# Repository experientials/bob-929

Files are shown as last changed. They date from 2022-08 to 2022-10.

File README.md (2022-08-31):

# Bob

Bob is an independent device that sees and senses the environment. It recognises objects and behavior based on what it has been taught. 

It receives stereo video input over 2 x 2-lane MIPI CSI2. Additionally it receives sensor input over I2C
for distance, color, brightness. The sensor inputs are processed and disected to identify objects, people and
behaviour. Ziloo can connect over USB to make the output available.

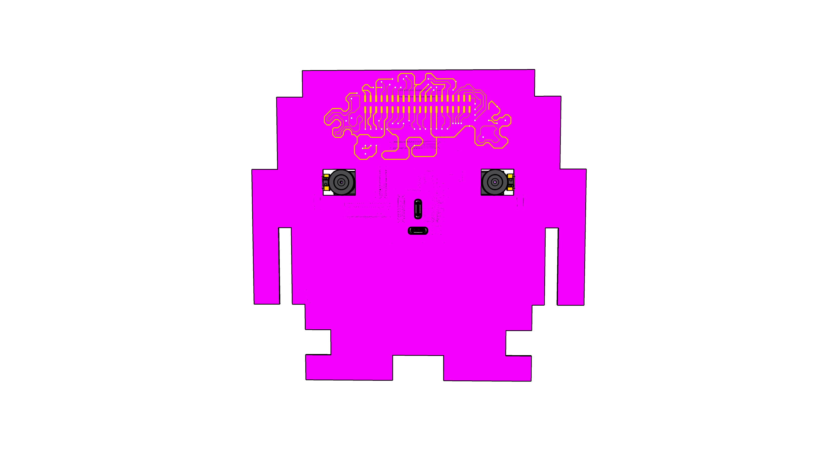
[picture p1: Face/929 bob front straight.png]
Bob face


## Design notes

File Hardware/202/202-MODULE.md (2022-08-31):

# 202 Combi Camera Module

The board
- 18mm x 57mm, 25mm wide hole for the T-USB module, 3.5mm bridge between the parts 
- 1 * 60 pin connector
- 2 * 34 pin connectors
- 34 pin connectors are 4.25 mm from bottom
- 34 pin connector centers are 51 mm apart
- 

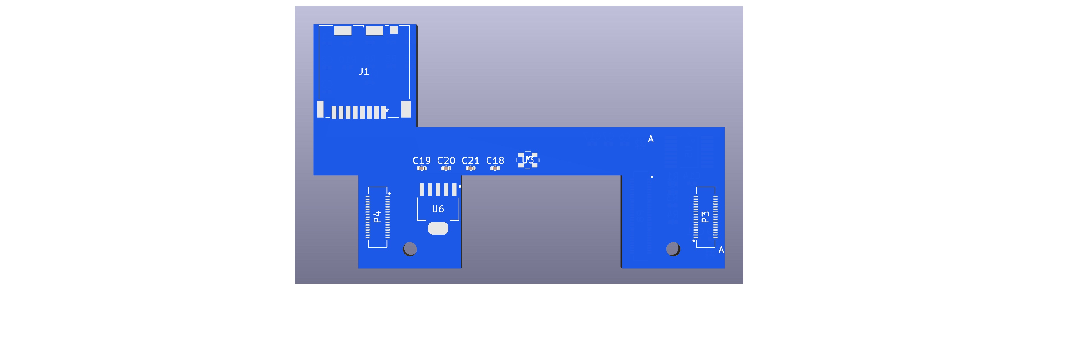
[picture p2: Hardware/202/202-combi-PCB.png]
202 Combi PCB


## BOM

- 1 * [XTAL OSC 24MHz ASE-24.000MHZ-LC-T]() - [Mouser](https://www.mouser.ch/ProductDetail/ABRACON/ASE-24.000MHZ-LC-T) - 1.2mm height - [Datasheet](https://abracon.com/Oscillators/ASEseries.pdf) - In stock
- 1 * [LDO Voltage Reg TPS79628DCQ 2.8V as SOT-223-6]() - [Mouser](https://www.mouser.ch/ProductDetail/Texas-Instruments/TPS79628DCQ) - In stock
- 1 * [IO Expander TCA9534PWR TSSOP 16 pin](https://www.ti.com/product/TCA9534) - 1.2mm height - [Datasheet](https://www.ti.com/lit/ds/symlink/tca9534.pdf) - In stock
- 1 * [Hirose Micro SD Card slot DM3CS-SF]() - [Mouser](https://www.mouser.ch/ProductDetail/Hirose-Connector/DM3CS-SF) - In stock
- 1 * [Ti Low Power MSP430 MCU MSP430FR2422IRHLR](https://www.ti.com/product/MSP430FR2422/part-details/MSP430FR2422IRHLR) - 15 GPIO - In stock
- 1 * [DF40C-60DP-0.4V]() [JLCPCB part](https://jlcpcb.com/parts/componentSearch?isSearch=true&searchTxt=DF40C-60DP-0.4V)
- 2 * [Hirose DF40C-34DS-0.4V](https://www.hirose.com/en/product/p/CL0684-4023-0-51) ([Mouser](https://www.mouser.ch/ProductDetail/Hirose-Connector/DF40C-34DS-04V51?qs=vcbW%252B4%252BSTIpg26DsEbj1iQ%3D%3D))

Component selection

- TPS796xx power reg vs RT8272 based on availability (Ti needs fewer components)
- TCA9534 over TCA9554 8-bit to save price. No apparent feature difference
- TCA9535 16-bit is SSOP/TSSOP in stock

Device tree and GPIO:

https://stackoverflow.com/questions/30130358/device-tree-and-gpio

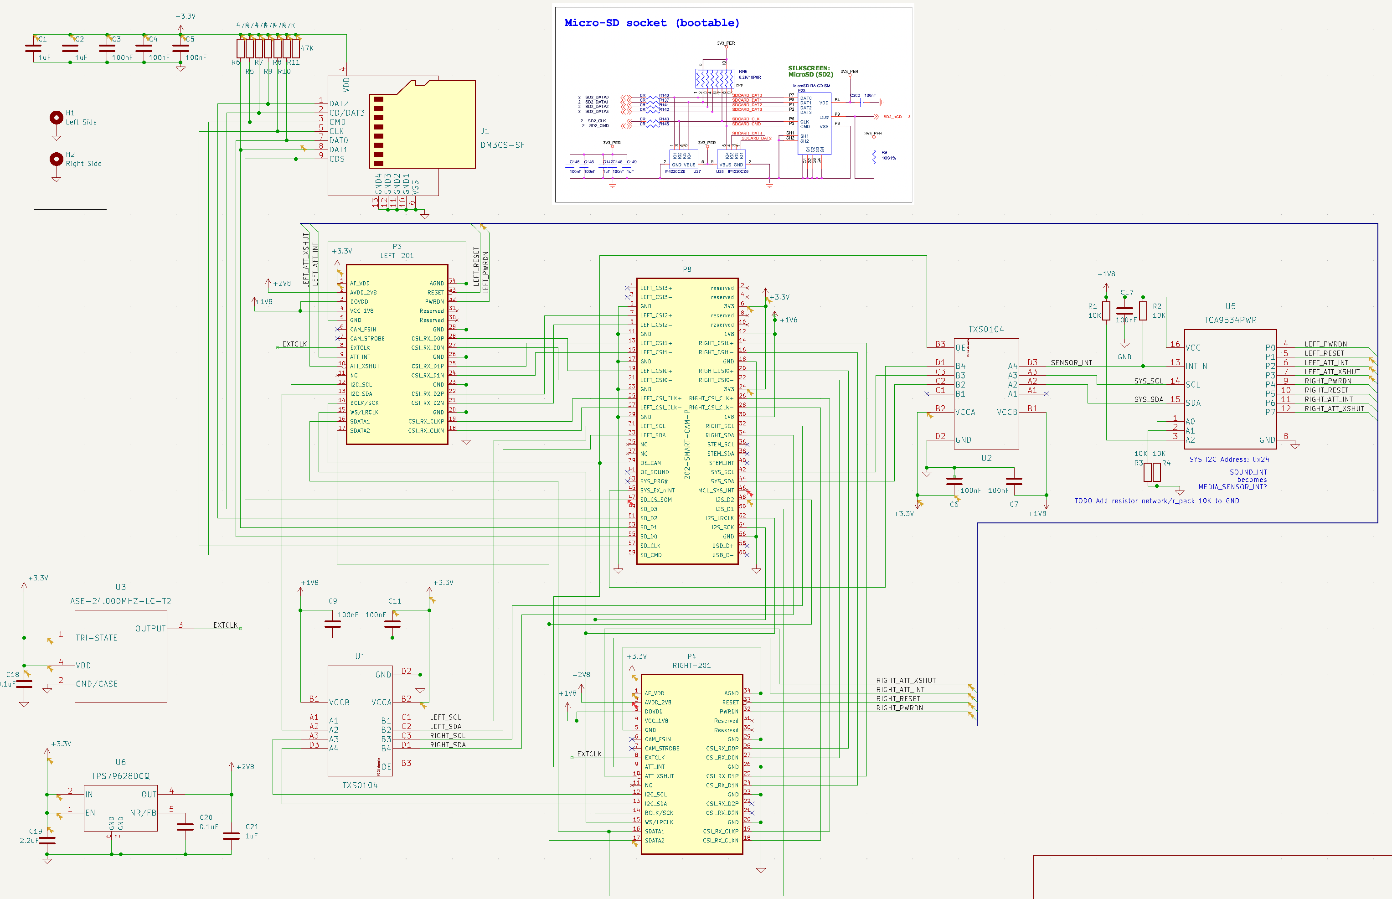
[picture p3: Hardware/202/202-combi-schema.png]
202 Combi Schema


## Upwork Job

You will revise my PCB design done with KiCAD v6. I have a schematic and basic PCB layout with the outline.
The board takes two connectors to camera modules and combine them into a single connector adding SD Card slot, I/O Expander, oscilator, voltage regulator and signal voltage translation.
I will want to add an MCU in the future so if you can reserve space for it on the board that will be very helpful.
I need a review for signal interference and quality of high speed signal lanes. I have not tried to route the
PCB, that will be your job.

- Correct design rules according to JLCPCB manufacturing
- Check the correctness of footprints against datasheets
- Check the need for capacitors on board reducing redundant ones
- Check that the schema/board has good ESD/noise reduction circuits
- Place resistors and capacitors where appropriate
- Update/Resolve Design checklist
- Ensure that differential pairs are routed together and balanced correctly
- Add 2 mounting holes next to P3 and P3 (symmetric)
- P3, P4 and P8 are aligned horizontally with overlapping centers
- Route the board

Symbols and footprints are found in https://github.com/experientials/kicad-lib.

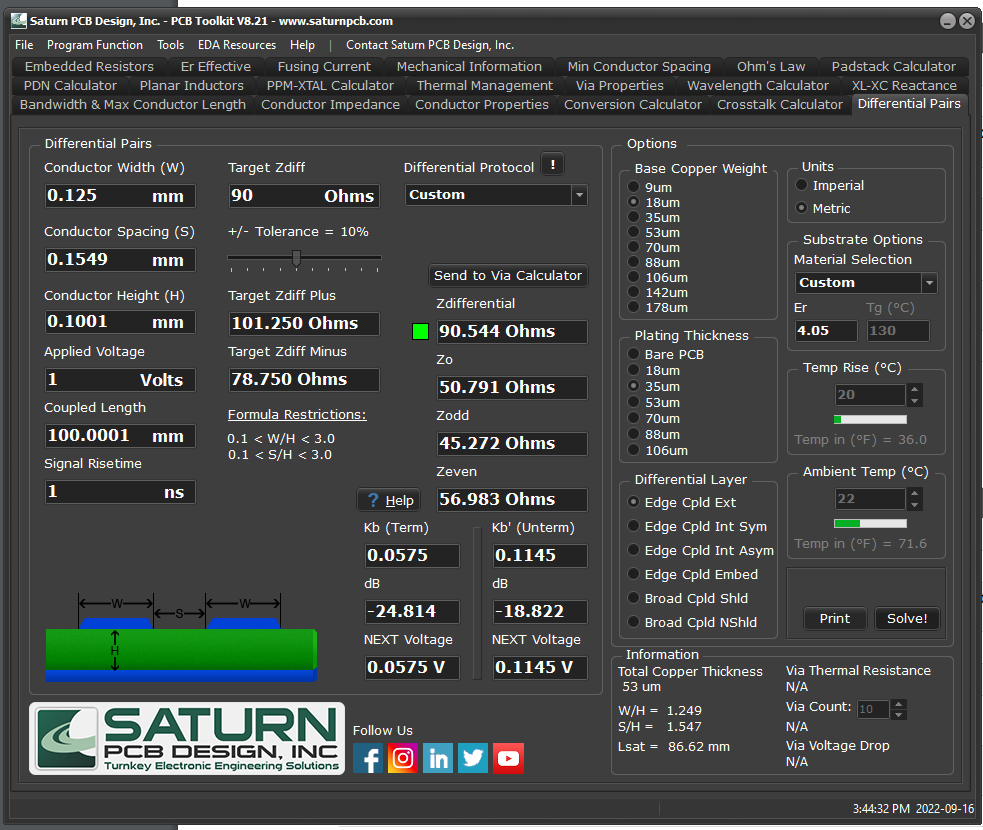
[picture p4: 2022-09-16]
Hardware/202/202-combi-v0.2/Stack-Up & Impendances/90Ohm_Diff.png

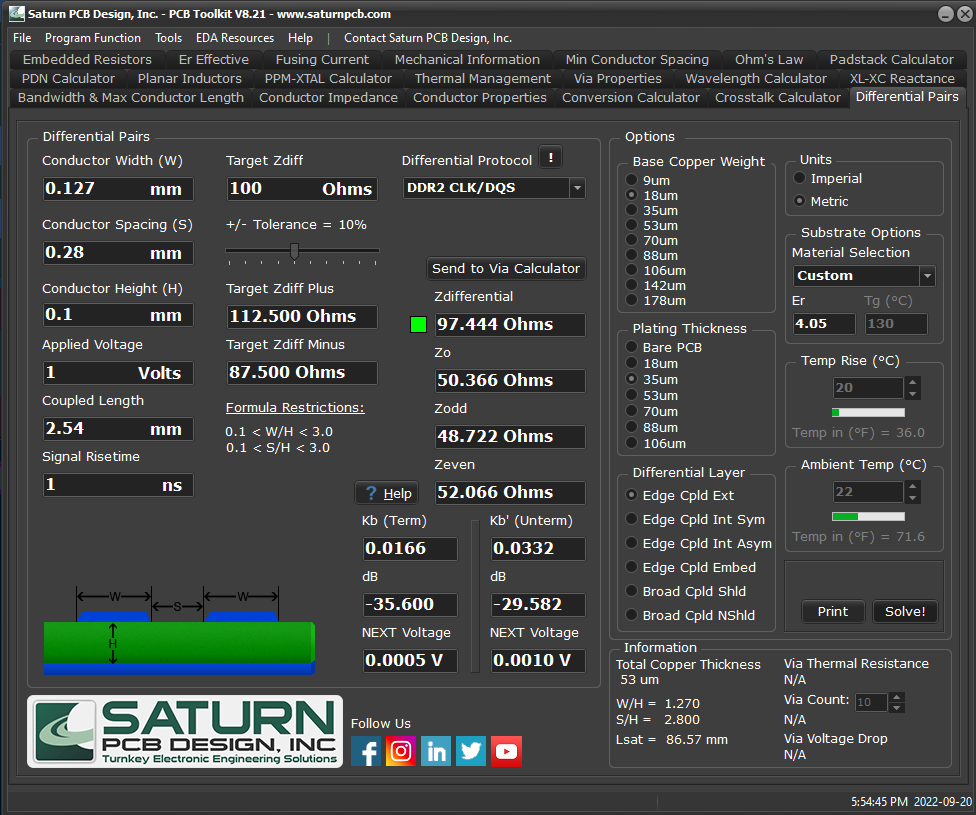
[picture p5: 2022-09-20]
Hardware/202/202-combi-v0.2/Stack-Up & Impendances/100Ohm_Diff.png

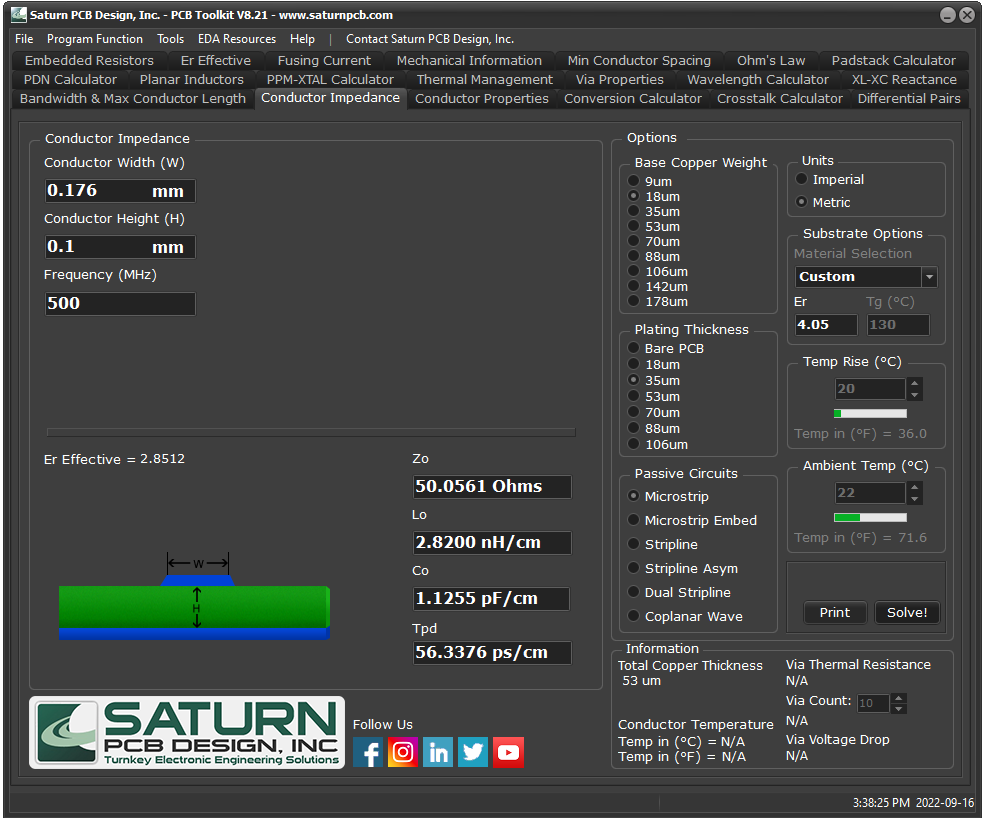
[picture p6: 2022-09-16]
Hardware/202/202-combi-v0.2/Stack-Up & Impendances/50Ohm_SE.png

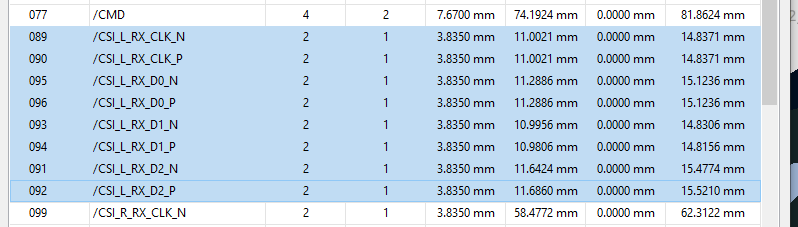
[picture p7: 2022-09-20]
Hardware/202/202-combi-v0.2/Stack-Up & Impendances/Left diff pair matching.png

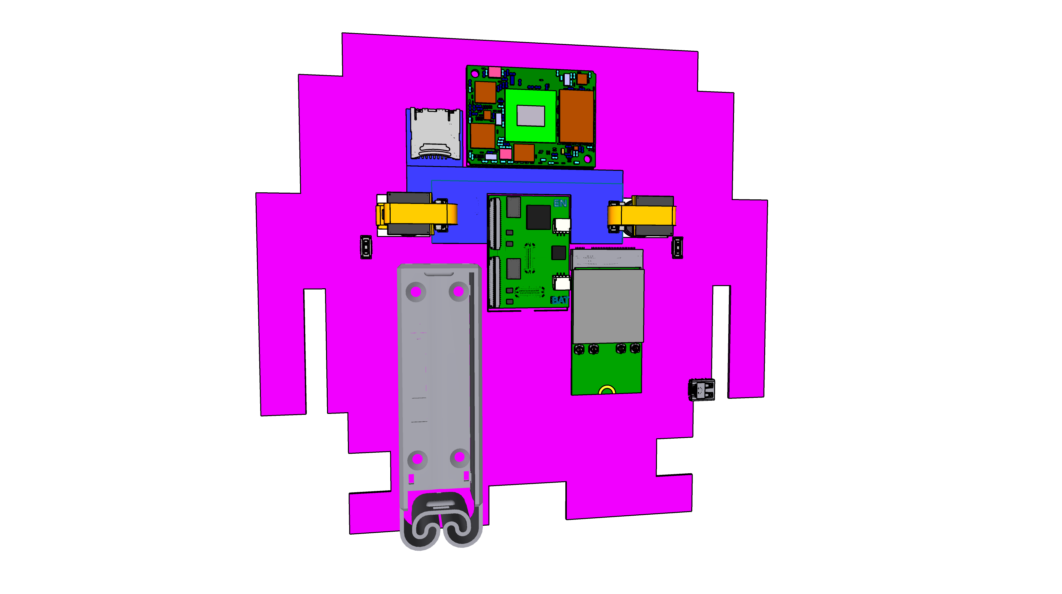
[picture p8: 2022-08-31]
Face/929 bob back.png

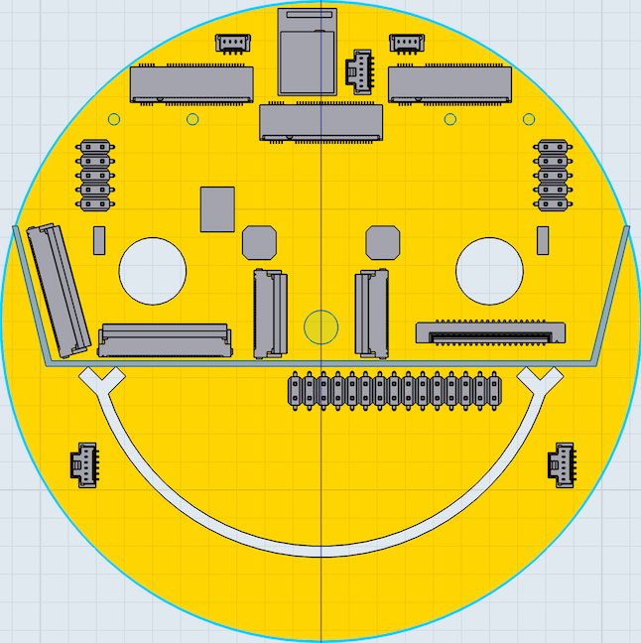
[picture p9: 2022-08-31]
Face/Ziloo back.png

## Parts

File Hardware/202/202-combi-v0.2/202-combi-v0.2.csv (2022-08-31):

Source: | /Volumes/Projects/ziloo/Hardware/202/202-combi/202-combi.kicad_sch
Date: | 2022 August 31, Wednesday 20:45:27
Tool: | Eeschema (6.0.6-0)
Generator: | /Applications/KiCad/KiCad.app/Contents/SharedSupport/plugins/bom_csv_grouped_by_value.py
Component Count: | 36
Individual Components:
Item | Qty | Reference(s) | Value | LibPart | Footprint | Datasheet | MANUFACTURER
 |  | C1 | 1uF | Device:C | Capacitor_SMD:C_0402_1005Metric | ~
 |  | C2 | 1uF | Device:C | Capacitor_SMD:C_0402_1005Metric | ~
 |  | C3 | 100nF | Device:C | Capacitor_SMD:C_0402_1005Metric | ~
 |  | C4 | 100nF | Device:C | Capacitor_SMD:C_0402_1005Metric | ~
 |  | C5 | 100nF | Device:C | Capacitor_SMD:C_0402_1005Metric | ~
 |  | C6 | 100nF | Device:C | Capacitor_SMD:C_0402_1005Metric | ~
 |  | C7 | 100nF | Device:C | Capacitor_SMD:C_0402_1005Metric | ~
 |  | C9 | 100nF | Device:C | Capacitor_SMD:C_0402_1005Metric | ~
 |  | C11 | 100nF | Device:C | Capacitor_SMD:C_0402_1005Metric | ~
 |  | C17 | 100nF | Device:C | Capacitor_SMD:C_0402_1005Metric | ~
 |  | C18 | 0.1uF | Device:C | Capacitor_SMD:C_0402_1005Metric | ~
 |  | C19 | 2.2uF | Device:C | Capacitor_SMD:C_0402_1005Metric | ~
 |  | C20 | 0.1uF | Device:C | Capacitor_SMD:C_0402_1005Metric | ~
 |  | C21 | 1uF | Device:C | Capacitor_SMD:C_0402_1005Metric | ~
 |  | H1 | Left Side | Mechanical:MountingHole_Pad | MountingHole:MountingHole_2.2mm_M2 | ~
 |  | H2 | Right Side | Mechanical:MountingHole_Pad | MountingHole:MountingHole_2.2mm_M2 | ~
 |  | J1 | DM3CS-SF | Ziloo:DM3CS-SF | Ziloo:DM3CS-SF
 |  | P3 | LEFT-201 | :201-SOCKET-34DS-0.4V(51)_1 | Ziloo:HIROSE_DF40C-34DS-0.4V(51) |  | Hirose Electric Co Ltd
 |  | P4 | RIGHT-201 | Ziloo:201-SOCKET-34DS-0.4V(51) | Ziloo:HIROSE_DF40C-34DS-0.4V(51) |  | Hirose Electric Co Ltd
 |  | P8 | 202-SMART-CAM-P | Ziloo:202-SMART-CAM-P | Ziloo:DF40C-60DP-0.4V51 | https://www.hirose.com/en/product/document?clcode=CL0684-4004-6-51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 | Hirose Electric Co Ltd
 |  | R1 | 10K | Device:R | Resistor_SMD:R_0402_1005Metric | ~
 |  | R2 | 10K | Device:R | Resistor_SMD:R_0402_1005Metric | ~
 |  | R3 | 10K | Device:R | Resistor_SMD:R_0402_1005Metric | ~
 |  | R4 | 10K | Device:R | Resistor_SMD:R_0402_1005Metric | ~
 |  | R5 | 47K | Device:R | Resistor_SMD:R_0402_1005Metric | ~
 |  | R6 | 47K | Device:R | Resistor_SMD:R_0402_1005Metric | ~
 |  | R7 | 47K | Device:R | Resistor_SMD:R_0402_1005Metric | ~
 |  | R8 | 47K | Device:R | Resistor_SMD:R_0402_1005Metric | ~
 |  | R9 | 47K | Device:R | Resistor_SMD:R_0402_1005Metric | ~
 |  | R10 | 47K | Device:R | Resistor_SMD:R_0402_1005Metric | ~
 |  | R11 | 47K | Device:R | Resistor_SMD:R_0402_1005Metric | ~
 |  | U1 | TXS0104 | Ziloo:TXS0104EYZTR | Ziloo:TXS0104EYZTR
 |  | U2 | TXS0104 | Ziloo:TXS0104EYZTR | Ziloo:TXS0104EYZTR
 |  | U3 | ASE-24.000MHZ-LC-T2 | Ziloo:ASE-24.000MHZ-LC-T2 | Ziloo:ASE-24.000MHZ-LC-T2
 |  | U5 | TCA9534PWR | Ziloo:TCA9534PWR | Ziloo:TCA9534PWR
 |  | U6 | TPS79628DCQ | Ziloo:TPS79628DCQ | Ziloo:SOT127P706X180-6N
Collated Components:
Item | Qty | Reference(s) | Value | LibPart | Footprint | Datasheet | MANUFACTURER
1 | 3 | C1, C2, C21 | 1uF | Device:C | Capacitor_SMD:C_0402_1005Metric | ~
2 | 8 | C3, C4, C5, C6, C7, C9, C11, C17 | 100nF | Device:C | Capacitor_SMD:C_0402_1005Metric | ~
3 | 2 | C18, C20 | 0.1uF | Device:C | Capacitor_SMD:C_0402_1005Metric | ~
4 | 1 | C19 | 2.2uF | Device:C | Capacitor_SMD:C_0402_1005Metric | ~
5 | 1 | H1 | Left Side | Mechanical:MountingHole_Pad | MountingHole:MountingHole_2.2mm_M2 | ~
6 | 1 | H2 | Right Side | Mechanical:MountingHole_Pad | MountingHole:MountingHole_2.2mm_M2 | ~
7 | 1 | J1 | DM3CS-SF | Ziloo:DM3CS-SF | Ziloo:DM3CS-SF
8 | 1 | P3 | LEFT-201 | :201-SOCKET-34DS-0.4V(51)_1 | Ziloo:HIROSE_DF40C-34DS-0.4V(51) |  | Hirose Electric Co Ltd
9 | 1 | P4 | RIGHT-201 | Ziloo:201-SOCKET-34DS-0.4V(51) | Ziloo:HIROSE_DF40C-34DS-0.4V(51) |  | Hirose Electric Co Ltd
10 | 1 | P8 | 202-SMART-CAM-P | Ziloo:202-SMART-CAM-P | Ziloo:DF40C-60DP-0.4V51 | https://www.hirose.com/en/product/document?clcode=CL0684-4004-6-51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 | Hirose Electric Co Ltd
11 | 4 | R1, R2, R3, R4 | 10K | Device:R | Resistor_SMD:R_0402_1005Metric | ~
12 | 7 | R5, R6, R7, R8, R9, R10, R11 | 47K | Device:R | Resistor_SMD:R_0402_1005Metric | ~
13 | 2 | U1, U2 | TXS0104 | Ziloo:TXS0104EYZTR | Ziloo:TXS0104EYZTR
14 | 1 | U3 | ASE-24.000MHZ-LC-T2 | Ziloo:ASE-24.000MHZ-LC-T2 | Ziloo:ASE-24.000MHZ-LC-T2
15 | 1 | U5 | TCA9534PWR | Ziloo:TCA9534PWR | Ziloo:TCA9534PWR
16 | 1 | U6 | TPS79628DCQ | Ziloo:TPS79628DCQ | Ziloo:SOT127P706X180-6N

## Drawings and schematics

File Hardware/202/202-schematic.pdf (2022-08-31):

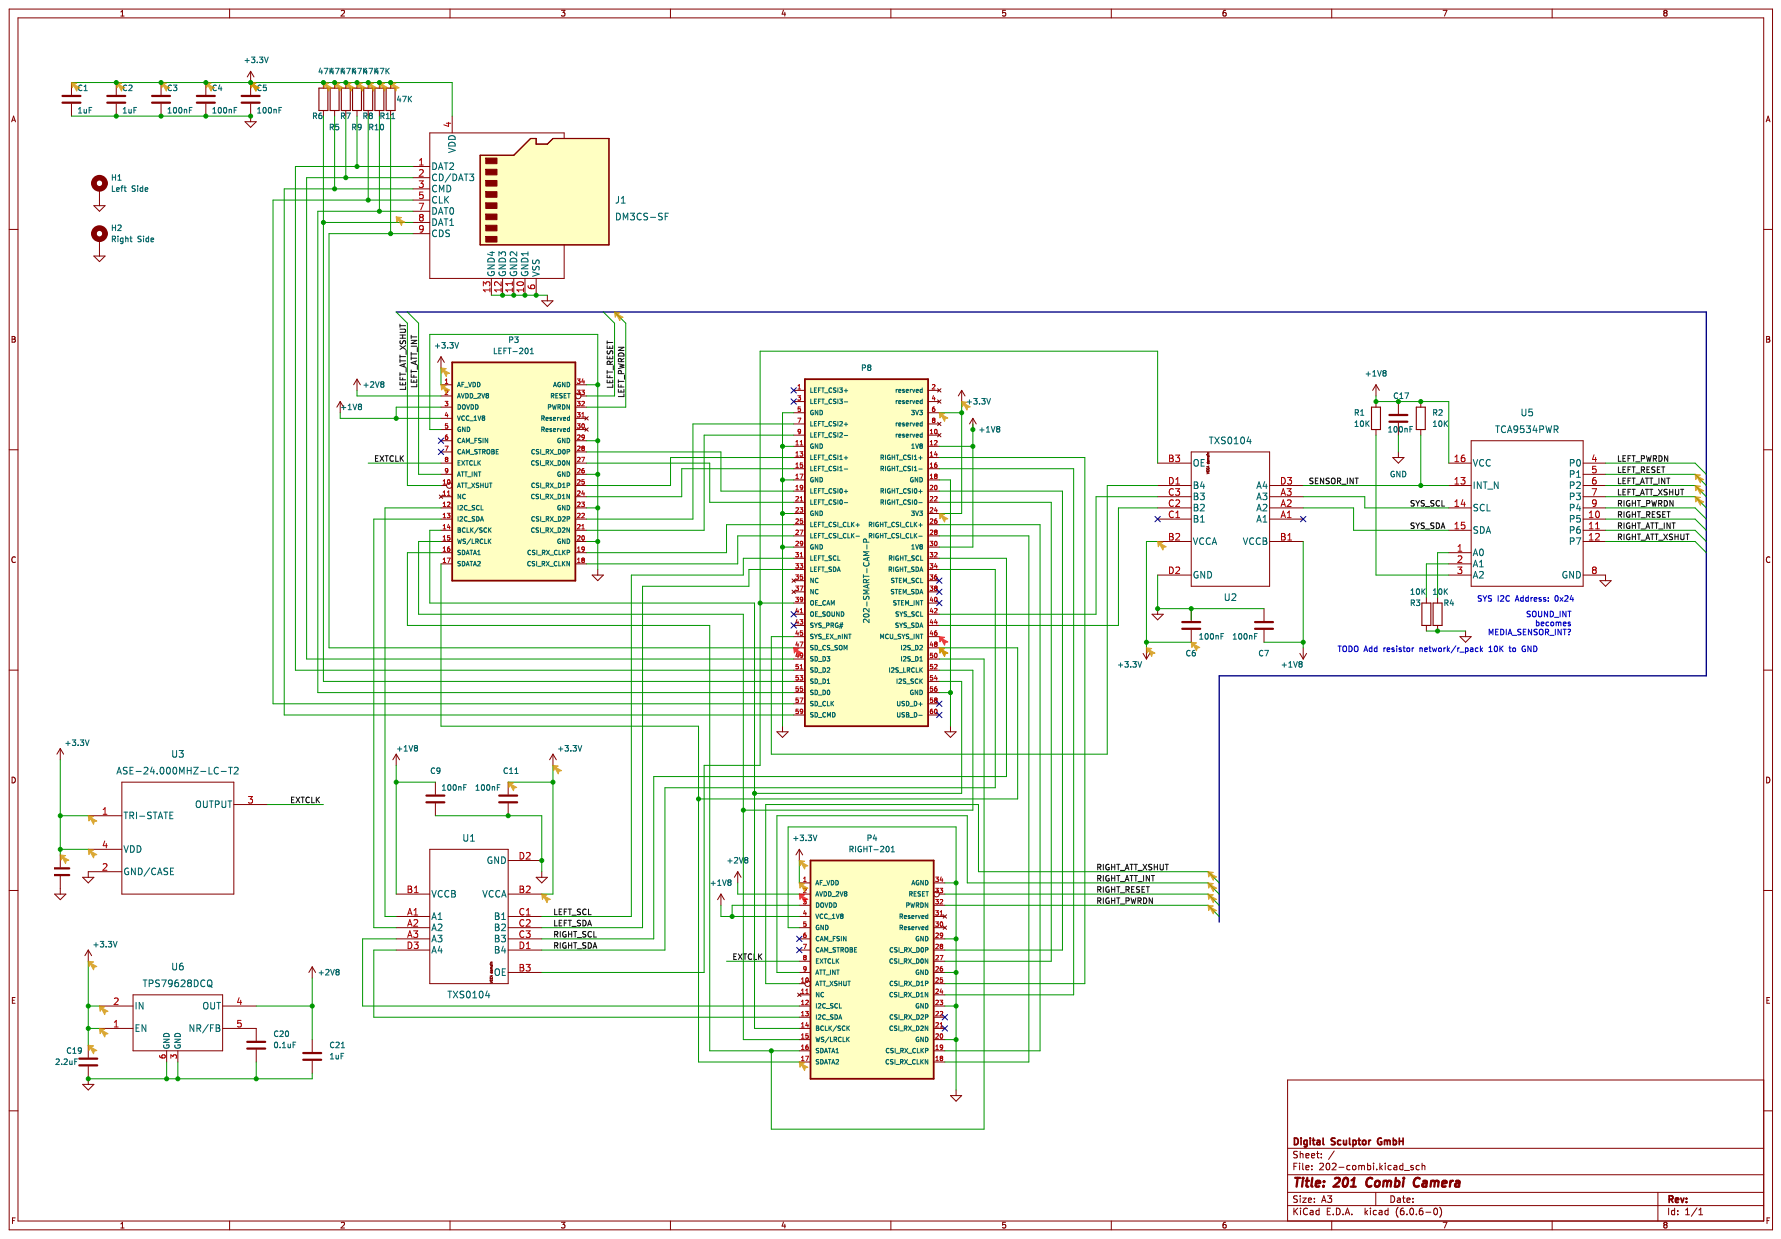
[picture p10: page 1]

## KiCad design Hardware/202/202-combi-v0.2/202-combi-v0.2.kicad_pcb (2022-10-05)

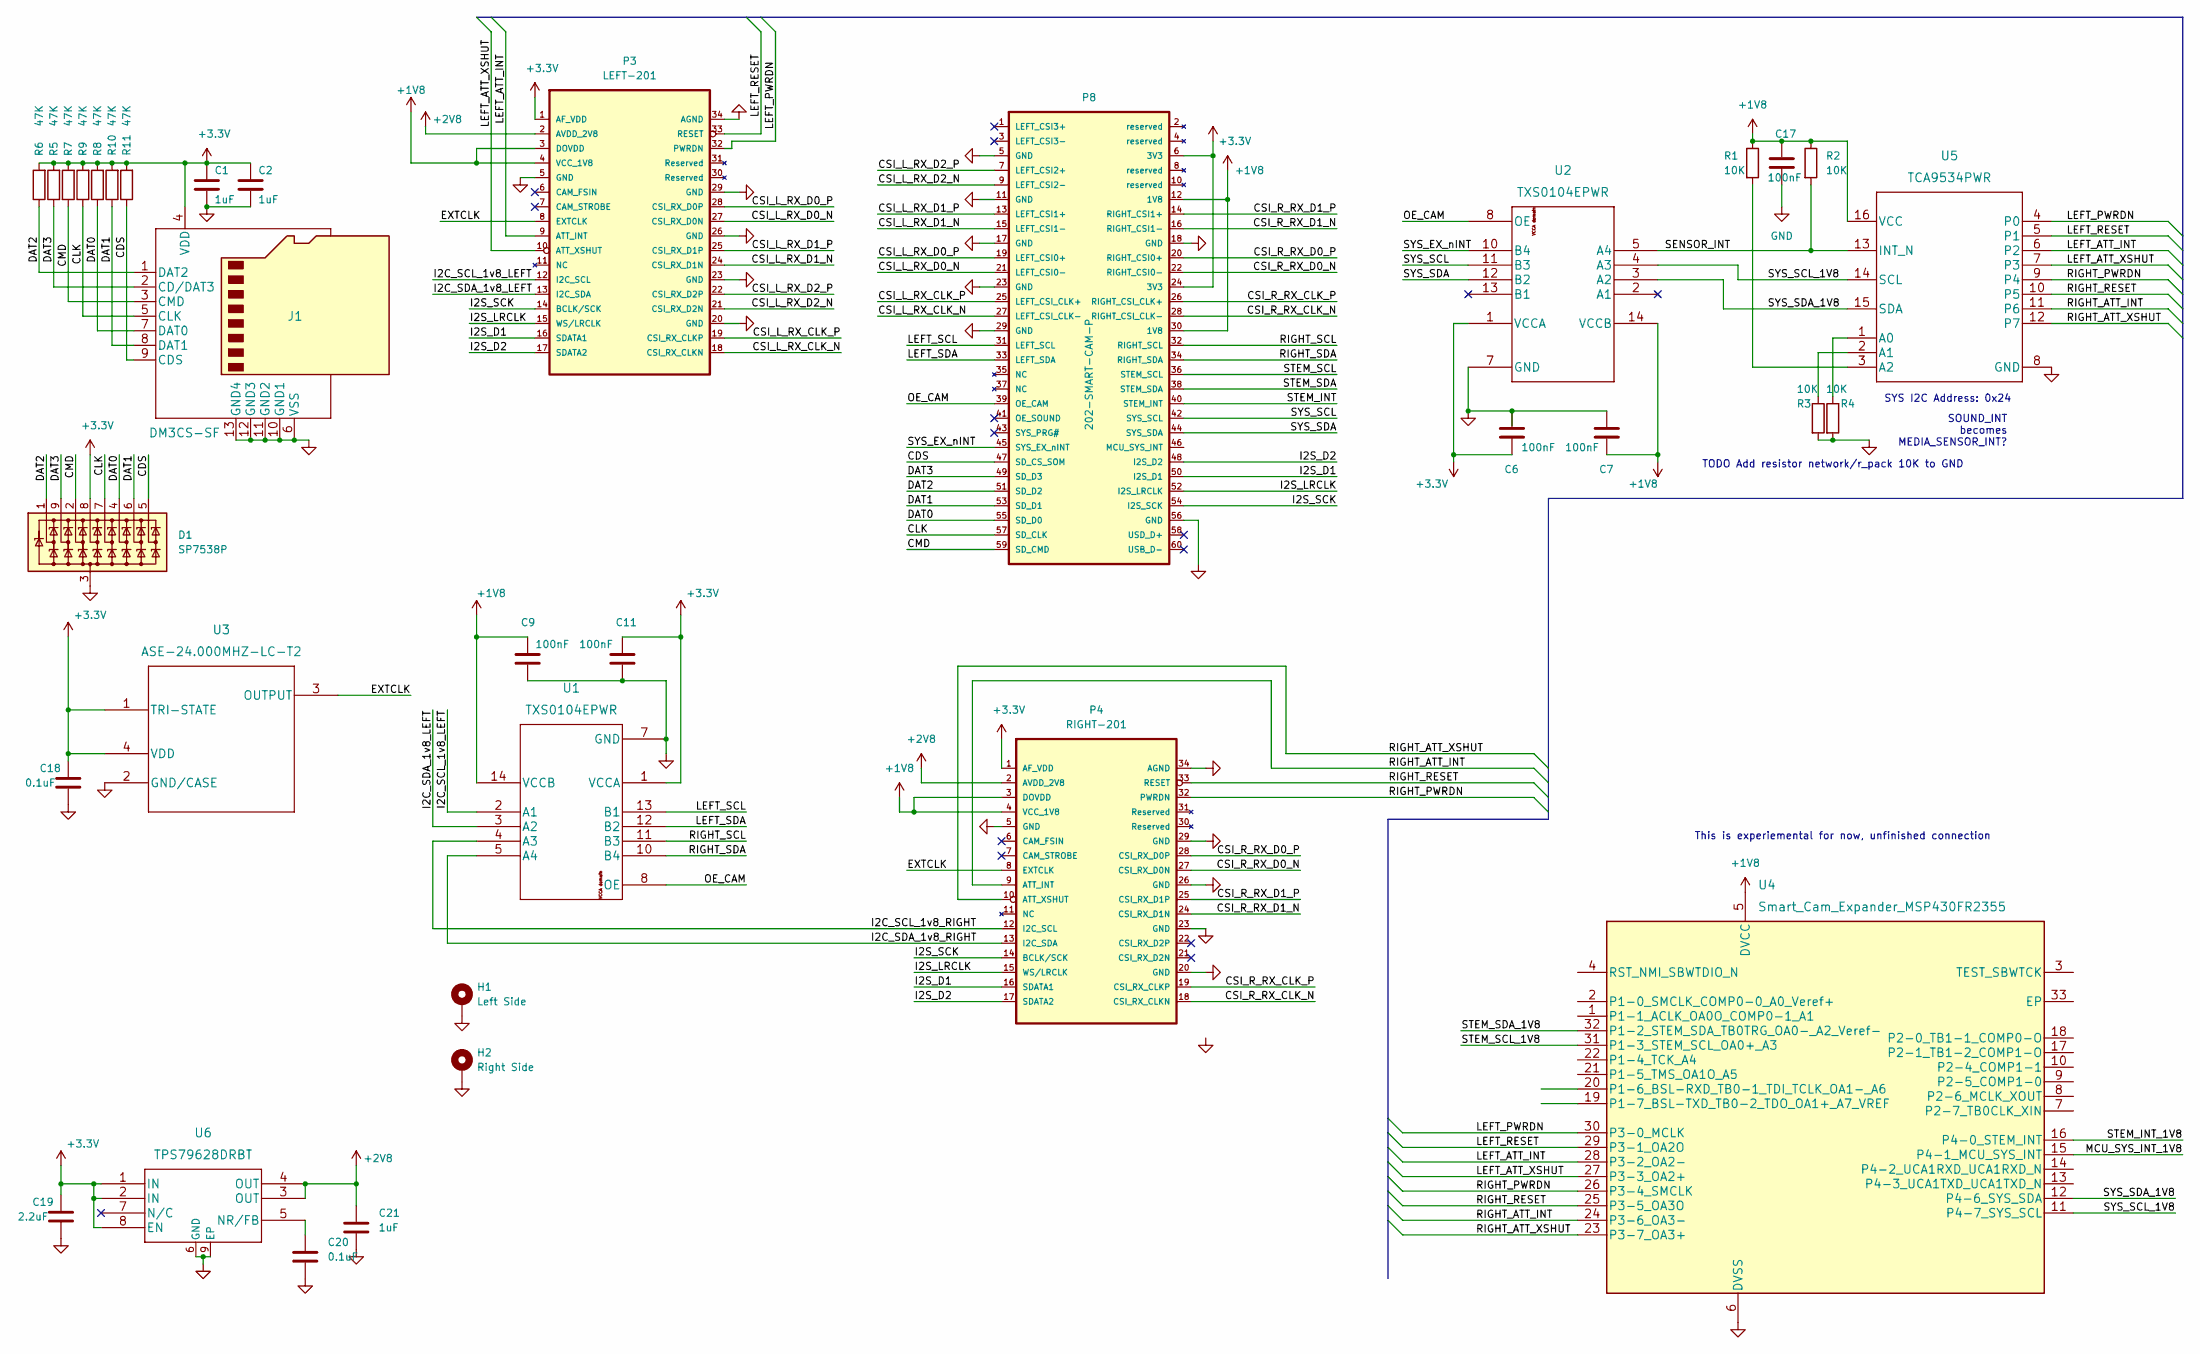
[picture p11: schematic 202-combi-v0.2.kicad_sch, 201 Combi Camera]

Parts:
C1, C2, C21: 1uF; C_0402_1005Metric
C6, C7, C9, C11, C17: 100nF; C_0402_1005Metric
C18, C20: 0.1uF; C_0402_1005Metric
C19: 2.2uF; C_0402_1005Metric
D1: SP7538P; UDFN-9_1.0x3.8mm_P0.5mm
H1: Left Side; MountingHole_2.2mm_M2
H2: Right Side; MountingHole_2.2mm_M2
J1: DM3CS-SF
P3: LEFT-201; HIROSE_DF40C-34DS-0.4V(51)_corrected
P4: RIGHT-201; HIROSE_DF40C-34DS-0.4V(51)_corrected
P8: 202-SMART-CAM-P; DF40C-60DP-0.4V51
R1, R2, R3, R4: 10K; R_0402_1005Metric
R5, R6, R7, R8, R9, R10, R11: 47K; R_0402_1005Metric
U1, U2: TXS0104EPWR; SSOP-14_5.3x6.2mm_P0.65mm
U3: ASE-24.000MHZ-LC-T2
U4: Smart_Cam_Expander_MSP430FR2355; MSP430FR2355TRSMR
U5: TCA9534PWR
U6: TPS79628DRBT; DFN-8-1EP_3x3mm_P0.65mm_EP1.7x2.05mm

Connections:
+1V8: C7.1, C9.1, C17.2, P3.3 (DOVDD), P3.4 (VCC_1V8), P4.3 (DOVDD), P4.4 (VCC_1V8), P8.12 (1V8), P8.30 (1V8), R1.1, R2.1, U1.14 (VCCB), U2.14 (VCCB), U4.5 (DVCC), U5.16 (VCC)
+2V8: C21.1, P3.2 (AVDD_2V8), P4.2 (AVDD_2V8), U6.3 (OUT), U6.4 (OUT)
+3.3V: C1.2, C2.2, C6.1, C11.1, C18.1, C19.1, D1.8 (K7), J1.4 (VDD), P3.1 (AF_VDD), P4.1 (AF_VDD), P8.6 (3V3), P8.24 (3V3), R5.2, R6.2, R7.2, R8.2, R9.2, R10.2, R11.2, U1.1 (VCCA), U2.1 (VCCA), U3.1 (TRI-STATE), U3.4 (VDD), U6.1 (IN), U6.2 (IN), U6.8 (EN)
/CDS: D1.5 (K4), J1.9 (CDS), P8.47 (SD_CS_SOM), R11.1
/CLK: D1.7 (K6), J1.5 (CLK), P8.57 (SD_CLK), R8.1
/CMD: D1.2 (K2), J1.3 (CMD), P8.59 (SD_CMD), R7.1
/CSI_L_RX_CLK_N: P3.18 (CSI_RX_CLKN), P8.27 (LEFT_CSI_CLK-)
/CSI_L_RX_CLK_P: P3.19 (CSI_RX_CLKP), P8.25 (LEFT_CSI_CLK+)
/CSI_L_RX_D0_N: P3.27 (CSI_RX_D0N), P8.21 (LEFT_CSI0-)
/CSI_L_RX_D0_P: P3.28 (CSI_RX_D0P), P8.19 (LEFT_CSI0+)
/CSI_L_RX_D1_N: P3.24 (CSI_RX_D1N), P8.15 (LEFT_CSI1-)
/CSI_L_RX_D1_P: P3.25 (CSI_RX_D1P), P8.13 (LEFT_CSI1+)
/CSI_L_RX_D2_N: P3.21 (CSI_RX_D2N), P8.9 (LEFT_CSI2-)
/CSI_L_RX_D2_P: P3.22 (CSI_RX_D2P), P8.7 (LEFT_CSI2+)
/CSI_R_RX_CLK_N: P4.18 (CSI_RX_CLKN), P8.28 (RIGHT_CSI_CLK-)
/CSI_R_RX_CLK_P: P4.19 (CSI_RX_CLKP), P8.26 (RIGHT_CSI_CLK+)
/CSI_R_RX_D0_N: P4.27 (CSI_RX_D0N), P8.22 (RIGHT_CSI0-)
/CSI_R_RX_D0_P: P4.28 (CSI_RX_D0P), P8.20 (RIGHT_CSI0+)
/CSI_R_RX_D1_N: P4.24 (CSI_RX_D1N), P8.16 (RIGHT_CSI1-)
/CSI_R_RX_D1_P: P4.25 (CSI_RX_D1P), P8.14 (RIGHT_CSI1+)
/DAT0: D1.4 (K3), J1.7 (DAT0), P8.55 (SD_D0), R9.1
/DAT1: D1.6 (K5), J1.8 (DAT1), P8.53 (SD_D1), R10.1
/DAT2: D1.1 (K1), J1.1 (DAT2), P8.51 (SD_D2), R5.1
/DAT3: D1.9 (K8), J1.2 (CD/DAT3), P8.49 (SD_D3), R6.1
/EXTCLK: P3.8 (EXTCLK), P4.8 (EXTCLK), U3.3 (OUTPUT)
/I2C_SCL_1v8_LEFT: P3.12 (I2C_SCL), U1.2 (A1)
/I2C_SCL_1v8_RIGHT: P4.12 (I2C_SCL), U1.4 (A3)
/I2C_SDA_1v8_LEFT: P3.13 (I2C_SDA), U1.3 (A2)
/I2C_SDA_1v8_RIGHT: P4.13 (I2C_SDA), U1.5 (A4)
/I2S_D1: P3.16 (SDATA1), P4.16 (SDATA1), P8.50 (I2S_D1)
/I2S_D2: P3.17 (SDATA2), P4.17 (SDATA2), P8.48 (I2S_D2)
/I2S_LRCLK: P3.15 (WS/LRCLK), P4.15 (WS/LRCLK), P8.52 (I2S_LRCLK)
/I2S_SCK: P3.14 (BCLK/SCK), P4.14 (BCLK/SCK), P8.54 (I2S_SCK)
/LEFT_ATT_INT: P3.9 (ATT_INT), U4.28 (P3-2_OA2-), U5.6 (P2)
/LEFT_ATT_XSHUT: P3.10 (ATT_XSHUT), U4.27 (P3-3_OA2+), U5.7 (P3)
/LEFT_PWRDN: P3.32 (PWRDN), U4.30 (P3-0_MCLK), U5.4 (P0)
/LEFT_RESET: P3.33 (RESET), U4.29 (P3-1_OA2O), U5.5 (P1)
/LEFT_SCL: P8.31 (LEFT_SCL), U1.13 (B1)
/LEFT_SDA: P8.33 (LEFT_SDA), U1.12 (B2)
/MCU_SYS_INT_1V8: U4.15 (P4-1_MCU_SYS_INT)
/OE_CAM: P8.39 (OE_CAM), U1.8 (OE), U2.8 (OE)
/RIGHT_ATT_INT: P4.9 (ATT_INT), U4.24 (P3-6_OA3-), U5.11 (P6)
/RIGHT_ATT_XSHUT: P4.10 (ATT_XSHUT), U4.23 (P3-7_OA3+), U5.12 (P7)
/RIGHT_PWRDN: P4.32 (PWRDN), U4.26 (P3-4_SMCLK), U5.9 (P4)
/RIGHT_RESET: P4.33 (RESET), U4.25 (P3-5_OA3O), U5.10 (P5)
/RIGHT_SCL: P8.32 (RIGHT_SCL), U1.11 (B3)
/RIGHT_SDA: P8.34 (RIGHT_SDA), U1.10 (B4)
/SENSOR_INT: R2.2, U2.5 (A4), U5.13 (INT_N)
/STEM_INT: P8.40 (STEM_INT)
/STEM_INT_1V8: U4.16 (P4-0_STEM_INT)
/STEM_SCL: P8.36 (STEM_SCL)
/STEM_SCL_1V8: U4.31 (P1-3_STEM_SCL_OA0+_A3)
/STEM_SDA: P8.38 (STEM_SDA)
/STEM_SDA_1V8: U4.32 (P1-2_STEM_SDA_TB0TRG_OA0-_A2_Veref-)
/SYS_EX_nINT: P8.45 (SYS_EX_nINT), U2.10 (B4)
/SYS_SCL: P8.42 (SYS_SCL), U2.11 (B3)
/SYS_SCL_1V8: U2.4 (A3), U4.11 (P4-7_SYS_SCL), U5.14 (SCL)
/SYS_SDA: P8.44 (SYS_SDA), U2.12 (B2)
/SYS_SDA_1V8: U2.3 (A2), U4.12 (P4-6_SYS_SDA), U5.15 (SDA)
GND: C1.1, C2.1, C6.2, C7.2, C9.2, C11.2, C17.1, C18.2, C19.2, C20.2, C21.2, D1.3 (A), H1.1, H2.1, J1.6 (VSS), J1.10 (GND1), J1.11 (GND2), J1.12 (GND3), J1.13 (GND4), P3.5 (GND), P3.20 (GND), P3.23 (GND), P3.26 (GND), P3.29 (GND), P3.34 (AGND), P4.5 (GND), P4.20 (GND), P4.23 (GND), P4.26 (GND), P4.29 (GND), P4.34 (AGND), P8.5 (GND), P8.11 (GND), P8.17 (GND), P8.18 (GND), P8.23 (GND), P8.29 (GND), P8.56 (GND), R3.2, R4.2, U1.7 (GND), U2.7 (GND), U3.2 (GND/CASE), U4.6 (DVSS), U4.33 (EP), U5.8 (GND), U6.6 (GND), U6.9 (EP)
unnamed: C20.1, U6.5 (NR/FB)
unnamed: R1.2, U5.3 (A2)
unnamed: R3.1, U5.2 (A1)
unnamed: R4.1, U5.1 (A0)

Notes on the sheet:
SOUND_INT becomes MEDIA_SENSOR_INT?
SYS I2C Address: 0x24
TODO Add resistor network/r_pack 10K to GND
This is experiemental for now, unfinished connection

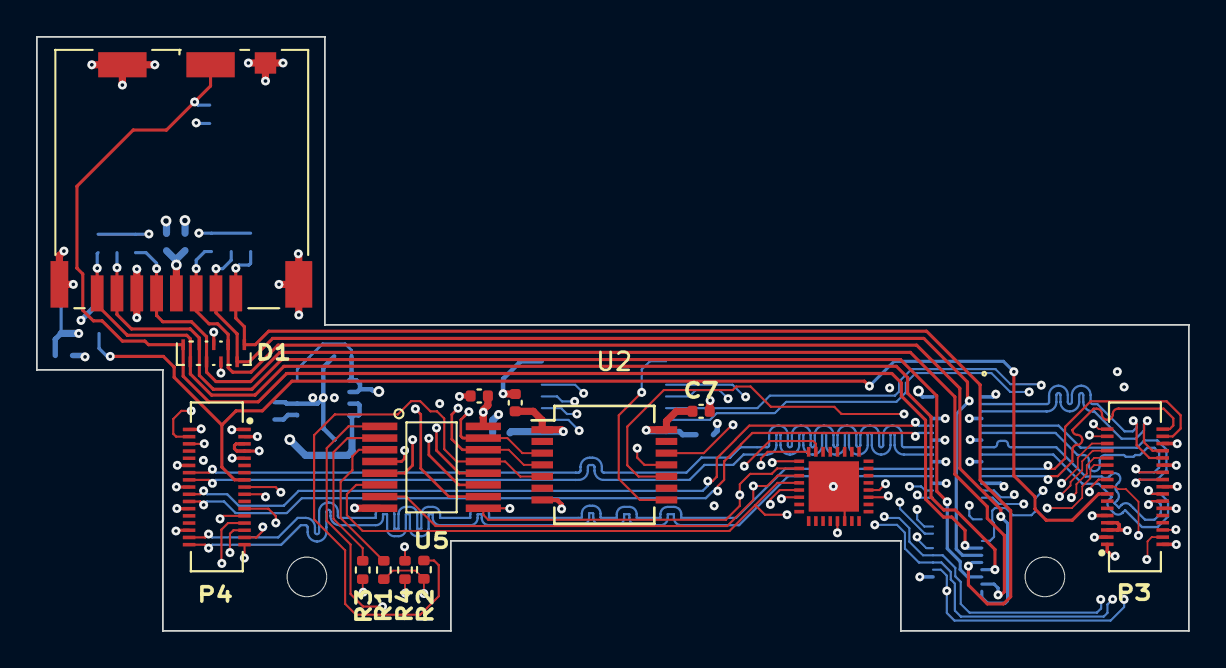
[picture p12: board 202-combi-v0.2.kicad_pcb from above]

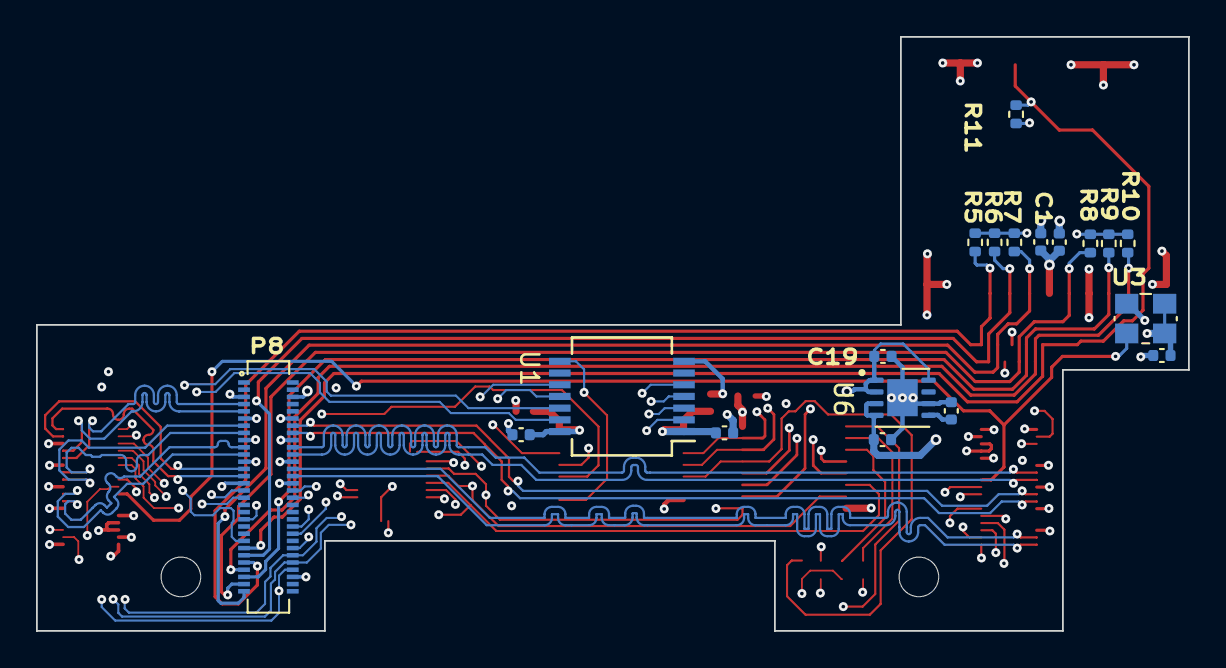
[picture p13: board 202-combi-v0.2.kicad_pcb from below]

Board: 6 copper layers, 64.0 x 33.0 mm, 35 parts (19 on the bottom side), 57 nets.

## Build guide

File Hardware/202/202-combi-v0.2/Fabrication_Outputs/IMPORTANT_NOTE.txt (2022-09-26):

When PCB is ordered make sure that its stack up is JLC3313

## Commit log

2022-08-31 Combined Camera module 202
    [202-combi.csv, 202-combi.kicad_pcb, 202-combi.kicad_sch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]
2022-09-02 Added MSP430
    This will be the only expander in the future. Experiment for now
    [202-combi.kicad_pcb, 202-combi.kicad_sch]
2022-09-16 Schematic clean-up
    -Cleaned-up shcematics
    -Added a TVS diode array to the SDCard connector.
    -Impedances are calculated
    [202-combi.kicad_pcb, 202-combi.kicad_sch]
2022-09-18 Add files via upload
    Mostly Routed
    [202-combi.kicad_pcb]
2022-09-20 Add files via upload
    ROuting completed, differential pairs are length matched and tuned
    [202-combi.kicad_pcb]
2022-09-26 Add files via upload
    - PCB is converted to 6-layer board
    - Differential pairs are routed and matched
    - Footprint of the LDO is changed to DFN (TPS79628DRBT is in use now)
    - Small changes which were causing DRC errors where corrected in Ziloo footprint library.
    [202-combi-v0.2-B_Cu.gbr, 202-combi-v0.2-B_Mask.gbr, 202-combi-v0.2-B_Paste.gbr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]

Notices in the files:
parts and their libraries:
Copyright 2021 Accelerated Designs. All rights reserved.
